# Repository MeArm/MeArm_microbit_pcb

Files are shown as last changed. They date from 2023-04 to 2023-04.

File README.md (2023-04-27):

## MeArm micro:bit Control Board PCB

<a href="https://shop.mearm.com/products/mearm-controller-board-for-micro-bit"><br/>
Click here to purchase one from the MeArm shop</a>

PCB files for the MeArm micro:bit Control Board PCB. Format is KiCad schematic and board layout
* https://shop.mearm.com/products/mearm-controller-board-for-micro-bit

### Description

This handy control board breaks uses pins P13, P14, P15, and P16 for controlling servo motors to manipulate a 4 axis robot arm. Pins P0, P1, P2, and P3 are used for analog inputs.

Disabling the LED matrix using the [following code](https://makecode.microbit.org/_8JDe2RcyMcPF) allows us to gain this extra functionality, and also times out the servo motors when they are not in use.

6V power can be supplied through a centre positive 2.1mm barrel jack. USB power is available but not advised if you're planning on moving quickly. 

### License

MeArm Robotics invests time and resources providing this open source design, please support MeArm Robotics and open-source hardware by purchasing products from [MeArm](https://www.mearm.com)!

Designed by Benjamin Gray/phenoptix for MeArm Robotics.

Creative Commons Attribution/Share-Alike, all text above must be included in any redistribution. See license.txt for additional details.

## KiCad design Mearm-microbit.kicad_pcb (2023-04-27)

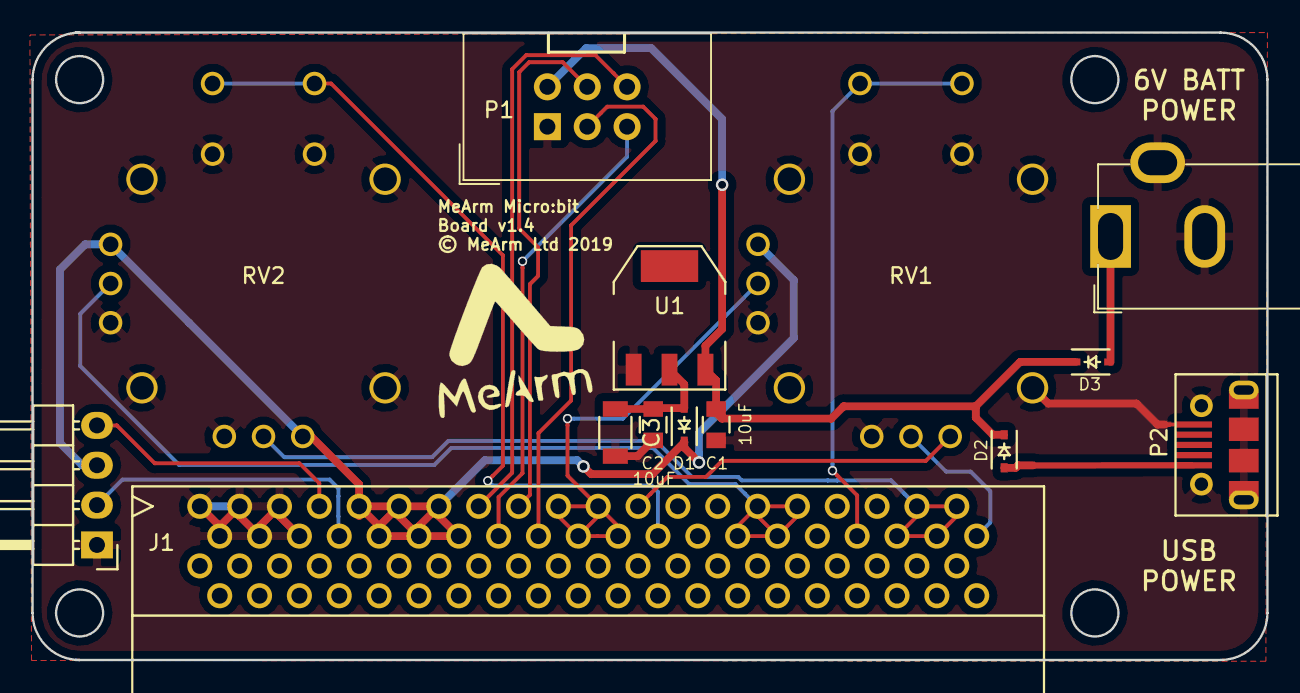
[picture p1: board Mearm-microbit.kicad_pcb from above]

Board: 2 copper layers, 78.7 x 40.0 mm, 13 parts (0 on the bottom side), 18 nets.

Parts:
C1, C2: 10uF; C_0805
C3: 100uF; C_1206
D1, D2, D3: BAT60AE6327; SOD-323
J1: microbit_edge_connector; Microbit_Connector_RA_TH
P1: CONN_02X03; IDC-Header_2x03_Pitch2.54mm_Straight
P2: USB_OTG; MOLEX_MICRO_USB
P4: CONN_01X04; Pin_Header_Angled_1x04
RV1, RV2: DUAL_POT_JOYSTICK; JOYSTICK
U1: LD1117S33CTR; SOT-223

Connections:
+3V3: D1.1, J1.17, J1.19, J1.21, J1.23, J1.25, J1.27, P4.3, RV1.6, RV2.1, RV2.6
+5V: C1.1, D2.1, D3.1, P1.2, U1.3
BASE_JOYSTICK: J1.71, J1.73, J1.75, J1.77, RV2.2
BASE_SERVO: J1.35, P1.3
BUTTON_A: J1.67, RV1.8
BUTTON_B: J1.47, RV2.8
GND: C1.2, C2.2, C3.2, J1.1, J1.3, J1.5, J1.7, J1.9, J1.11, P1.1, P2.5, P2.6, P4.1, RV1.3, RV1.4, RV1.7, RV1.9, RV2.3, RV2.4, RV2.7, RV2.9, U1.1
GRIP_JOYSTICK: J1.79, RV1.2
GRIP_JOY_ENABLE: J1.45, RV1.1
GRIP_SERVO: J1.29, P1.6
LEFT_JOYSTICK: J1.37, J1.39, J1.41, J1.43, RV1.5
LEFT_SERVO: J1.33, P1.4
unnamed: C2.1, C3.1, D1.2, U1.2
unnamed: D2.2, P2.1
RIGHT_JOYSTICK: J1.55, J1.57, J1.59, J1.61, RV2.5
RIGHT_SERVO: J1.31, P1.5
SCL: J1.15, P4.2
SDA: J1.13, P4.4

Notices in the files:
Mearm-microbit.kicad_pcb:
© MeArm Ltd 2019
